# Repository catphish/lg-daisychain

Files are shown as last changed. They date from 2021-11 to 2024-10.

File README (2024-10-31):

PLEASE NOTE: THIS PROJECT HAS BEEN REPLACED BY https://github.com/catphish/ti-daisychain-bms

BMS and CAN interface for bq76PL455A
====================================

This module permits batteries with bq76PL455A based slave boards to be balanced and monitored. Communication
with the battery slave modules takes place via the proprietary daisychain interface on each battery module.
Up to 16 batteries can be connected in a chain.

The module supports the following functionality:
* Automatic balancing of all cells in the chain
* Pack and cell voltages transmitted on CAN bus
* Temperatures transmitted via CAN bus
* Balancing target can be set via CAN or standalone

Standlone Balancing
===================

With jumper CONF2 open, the module will operate in standalone balancing mode. It will regularly monitor the
voltage of all attached cells, and will bleed any cell that meets BOTH of the following conditions.

* Voltage exceeds 4.0V
* Voltage is more than 10mV higher than the voltage of the lowest cell in the pack

For thermal safety, only one cell (wit the highest voltage) per battery will be discharged at a time.

CAN Balancing
=============

With jumper CONF2 closed, balancing is controlled by CAN bus messages. The module will bleed all cells
in the pack that exceed the voltage specified in the appropriate CAN message. Balancing halts after one
second, so messages must be received at least once per second to ensure continuous balancing. CAN messages
are docuented below.

For thermal safety, only one cell (wit the highest voltage) per battery will be discharged at a time.

Monitoring
==========

In all operating modes, the total pack voltage, individual cell voltages, and battery temperatures
are transmitted on the CAN bus. This can be used for external monitoring or to allow a third party
control unit to make decisions about balancing, charging, and safety limits. CAN messages are
docuented below.

Connections
===========

The following connections should be made. Each pair of wires should be twisted together (approx 360 degrees per inch).

1.CANL - Connect this to your CAN bus. On early boards this is mislabeled CANH.
2.CNAH - Connect this to your CAN bus. On early boards this is mislabeled CANL.
3.+12v - Positive power supply. This can be connected to a normal vehicle 12v supply or any power supply between 4v and 15v.
4.GND  - Connect to your common low voltage ground.

If you are using Arduino, all 4 connections can simply go to an Arduino CAN shield.

BATT - This should be connected to the battery chain. Only pins 1 & 2 are required. They
       should be twisted together in the same way as the CAN wiring. OEM cables are compatible.

1 ------------ 1
2 ------------ 2
3              3 (Connection not required but may be beneficial to cable strength)
4              4 (Connection not required but may be beneficial to cable strength)

Jumpers
=======

CAN_TERM - This jumper should be connected if this board is the final device in your CAN bus. Connect it if you
           are connecting direcly to one other device such as an Arduino. This will connect a 120 Ohm resistor
           between CANL and CANH.

CONF1    - If you intend to use two of these devices on the CAN bus, connect this jumper on the second device.
           This will change the CAN ID to avoid conflicts.

CONF2    - CAN controlled balancing. Close this jumper to disable the default policy of 4.0V and 10mV and instead
           allow balancing to be controlled via CAN bus.

CAN Messages Transmitted
========================

The adapter will transmit CAN messages in the following format:

ID      : 0x4f0 (0x4f1 if Jumper CONF1 is connected)
Byte 0  : Module ID (0-15)
Byte 1  : Cell ID (Measurements 0-15 of each module are cell voltages)
Byte 2-3: Cell voltage where 0x0000 is 0.0v and 0xffff is 5.0v. Big endian.

ID      : 0x4f0 (0x4f1 if Jumper CONF1 is connected)
Byte 0  : Module ID (0-15)
Byte 1  : Temperature sensor ID (Measurements 16-23 of each module are temperatures)
Byte 2-3: Outer temperature of battery module. Big endian. See table below for details.

ID      : 0x4f0 (0x4f1 if Jumper CONF1 is connected)
Byte 0  : Module ID (0-15)
Byte 1  : 0xff
Byte 2-3: Balancing bitmap. Identifies which cells are currently being dissharged. LSB is cell 0.

ID      : 0x4f0 (0x4f1 if Jumper CONF1 is connected)
Byte 0  : 0xff (Module 0xff is the adapter itself)
Byte 1  : 0xfe (Measurement ID 0xfe is pack voltage)
Byte 2-5: Pack voltage where 0x0000 is 0.0v and 0xffff is 5.0v. Big endian.

ID      : 0x4f0 (0x4f1 if Jumper CONF1 is connected)
Byte 0  : 0xff (Module 0xff is the adapter itself)
Byte 1  : 0xff (Measurement ID 0xff is status)
Byte 2  : Number of modules detected
Byte 3  : Communication error counter. If a module fails to respond, this counter is incremented and the whole chain is reset.

Additional sensors
==================

ID      Info
--      ----
16      AUX7 - Unknown - probably internal battery temperature sensor. Scale unknown.
17      External NTC - negative side.
18      External NTC - positive side.
19      PCB Temerature. Scale unknown but values above 1v (13107) are safe. Balancing is disabled by the adapter below this value.
20      PCB Temerature. Scale unknown but values above 1v (13107) are safe. Balancing is disabled by the adapter below this value.
21      PCB Temerature. Scale unknown but values above 1v (13107) are safe. Balancing is disabled by the adapter below this value.
22      PCB Temerature. Scale unknown but values above 1v (13107) are safe. Balancing is disabled by the adapter below this value.
23      AUX0 - probably unused. Reads close to 0v

External NTC sesors
===================

The following calculation can be used to convert the readong for an External NTC to a temperature:

float temperature(uint16_t adc) {
  float r = 0.0000000347363427499292f * adc * adc - 0.001025770762903f * adc + 2.68235340614337f;
  float t = log(r) * -30.5280964239816f + 95.6841501312447f;
  return t;
}

This code will not work for the PCB temperature sensors and will probably not work for AUX7.

CAN Messages Received
=====================

The adapter listens for CAN messages in the following format. This message will instruct cells in all modules with a measured
voltage above the specified voltage to self-discharge for a period of 1 second. The specified voltage would usually be the
voltage of the most discharged cell in the chain. This message must be received at least once per second (2Hz recommended) to
balance continuously. Note: For thermal safety, only one cell with the highest volage in each module will be discharged at a
time, but in time, all cells will discharge to the requested voltage.

ID      : 0x4f8 (note: all adapters will act regardless of CONF1 jumper)
Byte 0  : 0x00 (Balance)
Byte 1-2: Cell voltage threshold where 0x0000 is 0.0v and 0xffff is 5.0v

The following message will attempt to reset and re-identify all modules in the chain.
ID      : 0x4f8 (note: all adapters will reset regardless of CONF1 jumper)
Byte 0  : 0x01 (Reset)

The following message will cause the module and all slave modules to sleep in a low power state until a reset message is received
ID      : 0x4f8 (note: all adapters will sleep regardless of CONF1 jumper)
Byte 0  : 0x02 (Sleep)

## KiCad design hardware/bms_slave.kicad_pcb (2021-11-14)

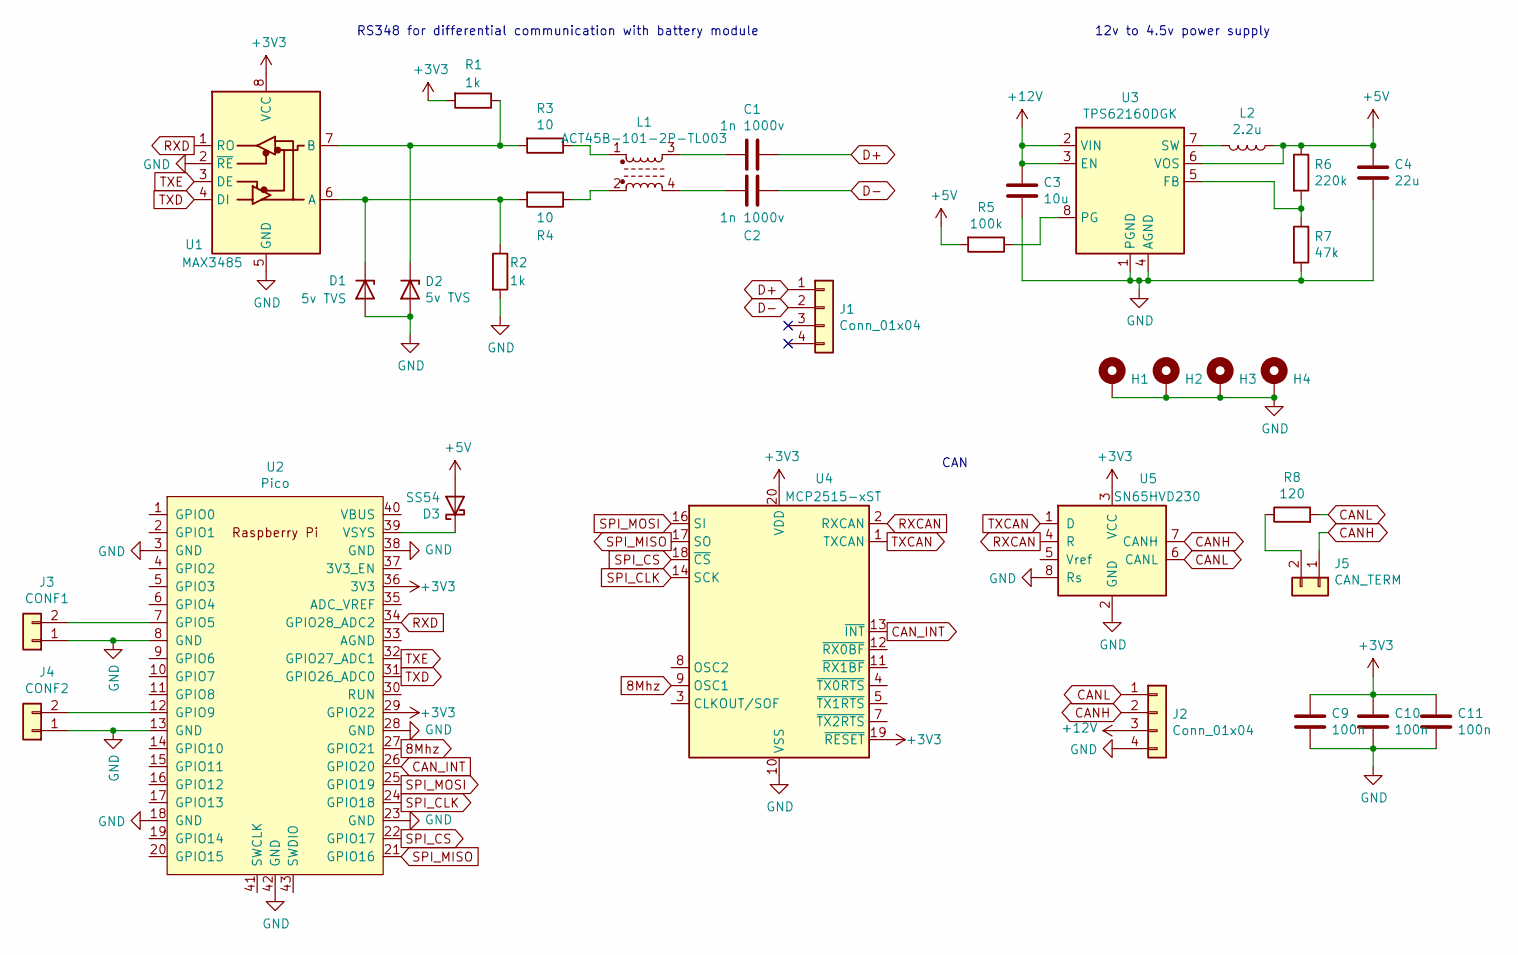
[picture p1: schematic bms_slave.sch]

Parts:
C1, C2: 1n 1000v; C_1206_3216Metric; LCSC C1941
C3: 10u; C_1210_3225Metric; LCSC C77102
C4: 22u; C_1206_3216Metric; LCSC C97950
C9, C10, C11: 100n; C_0603_1608Metric; LCSC C14663
D1, D2: 5v TVS; SOD882; LCSC C85401
D3: SS54; D_SMA; LCSC C22452
H1, H2, H3, H4: MountingHole; MountingHole_3.2mm_M3_Pad
J1, J2: Conn_01x04; SM04B1-CPTK-1A
J3: CONF1; PinHeader_1x02_P2.54mm_Vertical
J4: CONF2; PinHeader_1x02_P2.54mm_Vertical
J5: CAN_TERM; PinHeader_1x02_P2.54mm_Vertical
L1: ACT45B-101-2P-TL003; LCSC C88056
L2: 2.2u; 1227ASH100MP2; LCSC C435389
R1, R2: 1k; R_0603_1608Metric; LCSC C21190
R3, R4: 10; R_0603_1608Metric; LCSC C22859
R5: 100k; R_0603_1608Metric; LCSC C25803
R6: 220k; R_0603_1608Metric; LCSC C22961
R7: 47k; R_0603_1608Metric; LCSC C25819
R8: 120; R_1206_3216Metric; LCSC C17909
U1: MAX3485; SOP-8_3.9x4.9mm_P1.27mm; LCSC C18148
U2: Pico; RPi_Pico_SMD_TH
U3: TPS62160DGK; MSOP-8_3x3mm_P0.65mm; LCSC C60726
U4: MCP2515-xST; TSSOP-20_4.4x6.5mm_P0.65mm; LCSC C15193
U5: SN65HVD230; SOIC-8_3.9x4.9mm_P1.27mm; LCSC C12084

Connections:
8Mhz: U2.27 (GPIO21), U4.9 (OSC1)
+3V3: C9.1, C10.1, C11.1, R1.2, U1.8 (VCC), U2.29 (GPIO22), U2.36 (3V3), U4.19 (~RESET), U4.20 (VDD), U5.3 (VCC)
+5V: C4.1, D3.2 (A), L2.1, R5.2, R6.1, U3.6 (VOS)
+12V: C3.1, J2.3, U3.2 (VIN), U3.3 (EN)
CANH: J2.2, J5.1, U5.7 (CANH)
CANL: J2.1, R8.2, U5.6 (CANL)
CAN_INT: U2.26 (GPIO20), U4.13 (~INT)
D+: C1.1, J1.1
D-: C2.1, J1.2
GND: C3.2, C4.2, C9.2, C10.2, C11.2, D1.2 (A), D2.2 (A), H1.1, H2.1, H3.1, H4.1, J2.4, J3.1, J4.1, R2.2, R7.2, U1.2 (~RE), U1.5 (GND), U2.3 (GND), U2.8 (GND), U2.13 (GND), U2.18 (GND), U2.23 (GND), U2.28 (GND), U2.38 (GND), U2.42 (GND), U3.1 (PGND), U3.4 (AGND), U4.10 (VSS), U5.2 (GND), U5.8 (Rs)
unnamed: C1.2, L1.3
unnamed: C2.2, L1.4
unnamed: D1.1 (K), R2.1, R4.2, U1.6 (A)
unnamed: D2.1 (K), R1.1, R3.2, U1.7 (B)
unnamed: D3.1 (K), U2.39 (VSYS)
unnamed: J3.2, U2.7 (GPIO5)
unnamed: J4.2, U2.12 (GPIO9)
unnamed: J5.2, R8.1
unnamed: L1.1, R3.1
unnamed: L1.2, R4.1
unnamed: L2.2, U3.7 (SW)
unnamed: R5.1, U3.8 (PG)
unnamed: R6.2, R7.1, U3.5 (FB)
RXCAN: U4.2 (RXCAN), U5.4 (R)
RXD: U1.1 (RO), U2.34 (GPIO28_ADC2)
SPI_CLK: U2.24 (GPIO18), U4.14 (SCK)
SPI_CS: U2.22 (GPIO17), U4.18 (~CS)
SPI_MISO: U2.21 (GPIO16), U4.17 (SO)
SPI_MOSI: U2.25 (GPIO19), U4.16 (SI)
TXCAN: U4.1 (TXCAN), U5.1 (D)
TXD: U1.4 (DI), U2.31 (GPIO26_ADC0)
TXE: U1.3 (DE), U2.32 (GPIO27_ADC1)

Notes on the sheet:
RS348 for differential communication with battery module
12v to 4.5v power supply
CAN

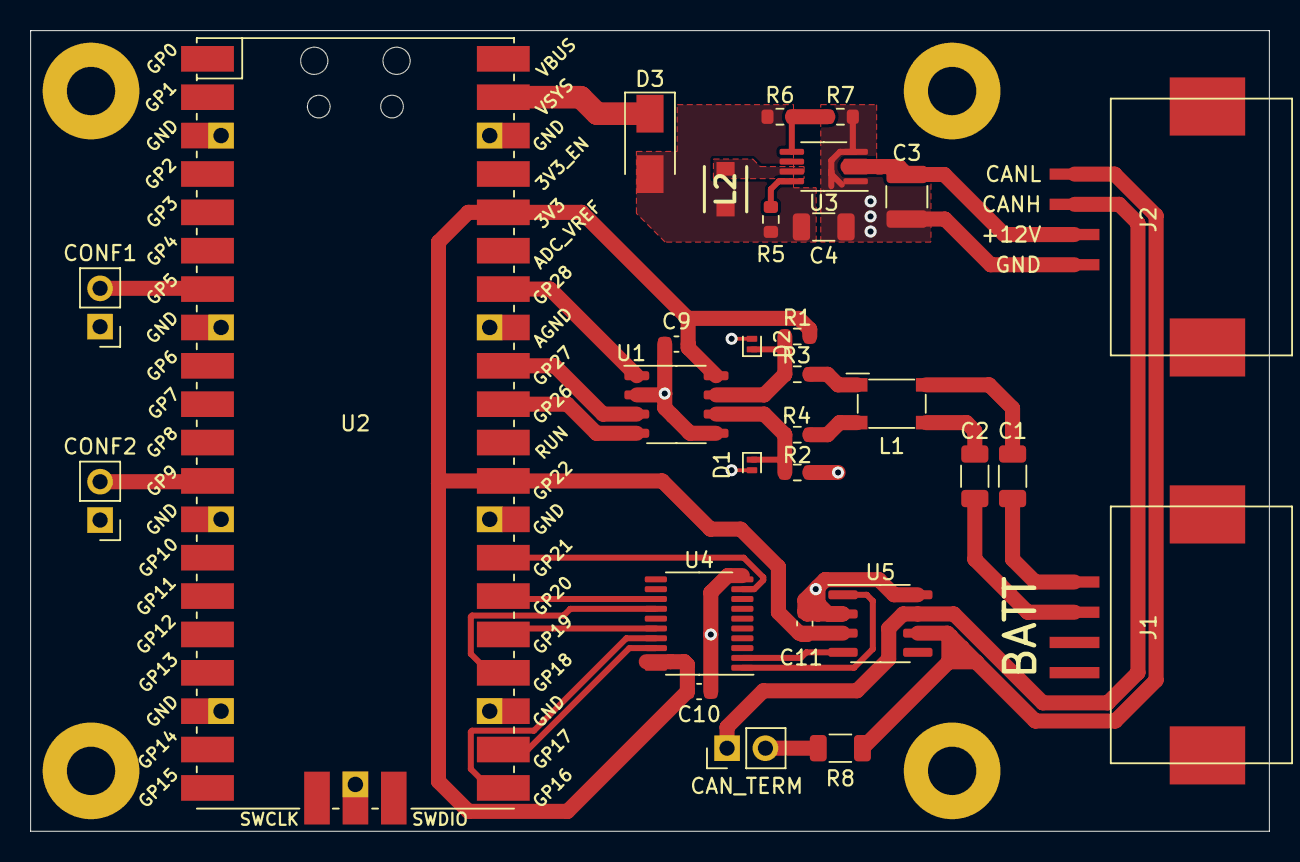
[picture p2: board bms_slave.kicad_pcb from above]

Board: 2 copper layers, 82.0 x 53.0 mm, 34 parts (0 on the bottom side), 32 nets.

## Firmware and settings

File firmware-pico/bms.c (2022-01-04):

#include <stdio.h>
#include "pico/stdlib.h"
#include "hardware/pio.h"
#include "hardware/spi.h"
#include "bms.pio.h"
#include "can.h"
#include <math.h>

// Min difference to enable balancing. 131 = 10mV
#define BALANCE_DIFF 131
// Min absolute voltage to enable balancing. 52428 = 4.0V, 53738 = 4.1V, 54525 = 4.16V
#define BALANCE_MIN 52428

// Define pins for SPI (to CAN)
#define SPI_PORT spi0
#define SPI_MISO 16
#define SPI_CS   17
#define SPI_CLK  18
#define SPI_MOSI 19
#define CAN_CLK  21 // 8MHz clock for CAN

// Define config pins
#define CONF1 5
#define CONF2 9

// Define pins for RS485 transceiver
#define SERIAL_IN     28
#define SERIAL_MASTER 27
#define SERIAL_OUT    26

// Buffers for received data
uint8_t rx_data_buffer[128];
uint8_t can_data_buffer[16];

// Other global variables
uint8_t module_count = 0;
uint8_t error_count = 0;
uint16_t balance_threshold = 0;
uint16_t cell_voltage[16][16];
uint16_t aux_voltage[16][8];
uint16_t balance_bitmap[16];
uint8_t balancing_mode;
uint16_t can_address;
uint8_t sleep_mode;
uint32_t pack_voltage;

// Variables for balancing process
uint16_t max_voltage;
uint16_t min_voltage;

// Timer
uint32_t sleep_period; // Time until next loop execution
uint8_t rewake;        // Whether the modules need to be woken up on next execution

// PIO and state machine selection
PIO pio = pio0;
#define SM_TX 0
#define SM_RX 1
#define SM_SQ 2

void SPI_configure() {
  spi_init(SPI_PORT, 1000000);
  spi_set_format(SPI_PORT, 8, 0,0,SPI_MSB_FIRST);
  gpio_set_function(SPI_MISO, GPIO_FUNC_SPI);
  gpio_set_function(SPI_MOSI, GPIO_FUNC_SPI);
  gpio_set_function(SPI_CLK, GPIO_FUNC_SPI);
  gpio_init(SPI_CS);
  gpio_set_dir(SPI_CS, GPIO_OUT);
  gpio_put(SPI_CS, 1);
}

void CAN_reset() {
  gpio_put(SPI_CS, 0);
  spi_write_blocking(SPI_PORT, (uint8_t[]){CMD_RESET},1);
  gpio_put(SPI_CS, 1);
  busy_wait_us(100);
}

uint8_t CAN_reg_read(uint8_t reg) {
  uint8_t data;
  gpio_put(SPI_CS, 0);
  spi_write_blocking(SPI_PORT, (uint8_t[]){CMD_READ, reg}, 2);
  spi_read_blocking(SPI_PORT, 0, &data, 1);
  gpio_put(SPI_CS, 1);
  return(data);
}

void CAN_reg_write(uint8_t reg, uint8_t val) {
  gpio_put(SPI_CS, 0);
  spi_write_blocking(SPI_PORT, (uint8_t[]){CMD_WRITE, reg, val}, 3);
  gpio_put(SPI_CS, 1);
}

void CAN_reg_modify(uint8_t reg, uint8_t mask, uint8_t val) {
  gpio_put(SPI_CS, 0);
  busy_wait_us(2);
  spi_write_blocking(SPI_PORT, (uint8_t[]){CMD_MODIFY, reg, mask, val}, 4);
  busy_wait_us(2);
  gpio_put(SPI_CS, 1);
}

void CAN_configure(uint16_t id) {
  // Configure speed to 500kbps based on 8MHz Crystal
  // Magic constants from https://github.com/sandeepmistry/arduino-CAN/blob/master/src/MCP2515.cpp
  CAN_reg_write(REG_CNF1, 0x00);
  CAN_reg_write(REG_CNF2, 0x90);
  CAN_reg_write(REG_CNF3, 0x02);

  // Enable Filters
  CAN_reg_write(REG_RXBnCTRL(0), 1<<2); // Enable rollover from BUF0 to BUF1
  CAN_reg_write(REG_RXBnCTRL(1), 0);
  // Set masks for RXB0 and RXB1 the same
  for(int n=0; n<2; n++) {
    uint16_t mask = 0x7ff;
    CAN_reg_write(REG_RXMnSIDH(n), mask >> 3);
    CAN_reg_write(REG_RXMnSIDL(n), mask << 5);
    CAN_reg_write(REG_RXMnEID8(n), 0);
    CAN_reg_write(REG_RXMnEID0(n), 0);
  }
  // Set match ID for all filters the same
  for(int n=0; n<6; n++) {
    CAN_reg_write(REG_RXFnSIDH(n), id >> 3);
    CAN_reg_write(REG_RXFnSIDL(n), id << 5);
    CAN_reg_write(REG_RXFnEID8(n), 0);
    CAN_reg_write(REG_RXFnEID0(n), 0);
  }

  // Set normal operation mode
  CAN_reg_write(REG_CANCTRL, MODE_NORMAL);
}

uint8_t CAN_receive(uint8_t * can_rx_data) {
  uint8_t intf = CAN_reg_read(REG_CANINTF);
  uint8_t rtr;
  uint8_t n; // One of two receive buffers
  if(intf & FLAG_RXnIF(0)) {
    n = 0;
  } else if (intf & FLAG_RXnIF(1)) {
    n = 1;
  } else {
    return 0;
  }
  rtr = (CAN_reg_read(REG_RXBnSIDL(n)) & FLAG_SRR) ? true : false;
  uint8_t dlc = CAN_reg_read(REG_RXBnDLC(n)) & 0x0f;

  uint8_t length;
  if (rtr) {
    length = 0;
  } else {
    length = dlc;

    for (int i = 0; i < length; i++)
      can_rx_data[i] = CAN_reg_read(REG_RXBnD0(n) + i);
  }

  CAN_reg_modify(REG_CANINTF, FLAG_RXnIF(n), 0x00);
  return(length);
}

void CAN_transmit(uint16_t id, uint8_t* data, uint8_t length) {
  CAN_reg_write(REG_TXBnSIDH(0), id >> 3); // Set CAN ID
  CAN_reg_write(REG_TXBnSIDL(0), id << 5); // Set CAN ID
  CAN_reg_write(REG_TXBnEID8(0), 0x00);    // Extended ID
  CAN_reg_write(REG_TXBnEID0(0), 0x00);    // Extended ID

  CAN_reg_write(REG_TXBnDLC(0), length);   // Frame length

  for (int i = 0; i < length; i++) {       // Write the frame data
    CAN_reg_write(REG_TXBnD0(0) + i, data[i]);
  }

  CAN_reg_write(REG_TXBnCTRL(0), 0x08);    // Start sending
  busy_wait_us(1000); // Allow up to 1ms to transmit
  CAN_reg_write(REG_TXBnCTRL(0), 0);    // Stop sending
  CAN_reg_modify(REG_CANINTF, FLAG_TXnIF(0), 0x00); // Clear interrupt flag
}

// Calculate message CRC.
uint16_t crc16(uint8_t * message, uint8_t length) {
  uint16_t crc = 0;
  uint16_t j;
  while (length--) {
    crc ^= *message++;
    for (j=0; j<8; j++) {
      crc = (crc >> 1) ^ ((crc & 1) ? 0xa001 : 0);
    }
  }
  return crc;
}

// Deactivate the TX PIO and send a square wave to wake up the device
void wakeup() {
  // Disable TX PIO
  pio_sm_set_enabled(pio, SM_TX, false);
  // Wait for it to be disabled
  busy_wait_ms(10);
  // Loop for 200 x 10us = 2ms
  for(int n=0; n<200; n++) {
    pio_sm_set_pins(pio, SM_TX, (1<<SERIAL_MASTER) | (0<<SERIAL_OUT)); // Drive DO low (DE enabled)
    busy_wait_us(4);
    pio_sm_set_pins(pio, SM_TX, (1<<SERIAL_MASTER) | (1<<SERIAL_OUT)); // Drive DO high (DE enabled)
    busy_wait_us(4);
  }
  pio_sm_set_pins(pio, SM_TX, (1<<SERIAL_MASTER) | (0<<SERIAL_OUT)); // Drive DO low (DE enabled)
  busy_wait_us(4);
  // Disable DE, stop driving bus
  pio_sm_set_pins(pio, SM_TX, 0);
  // Re-enable TX PIO
  pio_sm_set_enabled(pio, SM_TX, true);
  // Give the modules time to reset
  busy_wait_ms(200);
}

// Send a command string
void send_command(uint8_t* command, uint8_t length) {
  // Append framing but to the first byte and send it
  pio_sm_put_blocking(pio, SM_TX, command[0] | 0x100);
  // Send remaining bytes
  for(int n=1; n<length; n++)
    pio_sm_put_blocking(pio, SM_TX, command[n]);
  // Calculate and send CRC16
  uint16_t crc = crc16(command, length);
  pio_sm_put_blocking(pio, SM_TX, crc & 0xFF);
  pio_sm_put_blocking(pio, SM_TX, crc >> 8);
  busy_wait_us(20); // Always insert a short pause after sending commands
}

// Receive data from PIO into a local buffer, size limit and timeout in microseconds specified
// It's probably unnecessary to do this with an interrupt because we know when we expect to receive data
uint16_t receive_data(uint8_t* buffer, uint16_t size, uint32_t timeout) {
  uint16_t rx_data_offset = 0;
  // Return immediately if size is zero
  if(size == 0) return 0;
  // Loop until timeout expires
  for(int n=0; n<timeout; n++) {
    // Check for data in input FIFO
    while(!pio_sm_is_rx_fifo_empty(pio, SM_RX)) {
      // Receive one byte
      buffer[rx_data_offset++] = pio_sm_get_blocking(pio, SM_RX);
      // Return full size if we've filled the string
      if(rx_data_offset == size) return size;
    }
    // Sleep 1 microsecond each loop
    busy_wait_us(1);
  }
  // Return partial length received
  return rx_data_offset;
}

// Configure all daisychained packs with sequential addresses
void configure() {
  // Fully Enable Differential Interfaces and Select Auto-Addressing Mode
  send_command((uint8_t[]){0xF2,0x10,0x10,0xE0}, 4);
  // Configure the bq76PL455A-Q1 device to use auto-addressing to select address
  send_command((uint8_t[]){0xF1,0x0E,0x10}, 3);
  // Configure the bq76PL455A-Q1 device to enter auto-address mode
  send_command((uint8_t[]){0xF1,0x0C,0x08}, 3);
  // Configure 16 devices with sequential addresses
  for(int n=0; n<16; n++) {
    send_command((uint8_t[]){0xF1,0x0A,n}, 3);
  }
  for(int n=0; n<16; n++) {
    // Attempt to read back the address from each device
    pio_sm_clear_fifos(pio, SM_RX);
    send_command((uint8_t[]){0x81,n,0x0A,0x00}, 4);
    uint16_t received = receive_data(rx_data_buffer, 4, 10000);
    // If we don't receive a response, assume there are no more modules
    // and return the number of modules successfully found.
    if(received != 4) {
      module_count = n;
      return;
    }
  }
  module_count = 16;
}

// Request that all packs simultaneously sample voltage
void sample_all() {
  // 0xFF 0xFF 0xFF - these 24 bits enable sampling of 16 cell voltages and
  //                  8 AUX channels. Some will contain temperature data.
  //                  16x oversampling.
  send_command((uint8_t[]){0xF6,0x02,0x00,0xFF,0xFF,0xFF,0x00,0x04}, 8);
  busy_wait_ms(10);
}

// Put all modules to sleep
void sleep_modules() {
  send_command((uint8_t[]){0xF1,0x0C,0x48}, 3);
  rewake = 1;
}

// Return 1 if all PCB temperature sensors on a module are above 1.0v
uint8_t pcb_below_temp(uint8_t module) {
  if(aux_voltage[module][3] < 13107) return 0;
  if(aux_voltage[module][4] < 13107) return 0;
  if(aux_voltage[module][5] < 13107) return 0;
  if(aux_voltage[module][6] < 13107) return 0;
  return 1;
}

float temperature(uint16_t adc) {
  float r = adc;
  r = r * r * 0.0000000347363427499292f - r * 0.001025770762903f + 2.68235340614337f;
  float t = logf(r) * -30.5280964239816f + 95.6841501312447f;
  return t;
}

int main()
{
  // Set system clock to 80MHz, this seems like a reasonable value for the 4MHz data
  set_sys_clock_khz(80000, true);
  // Configure STDIO for debugging
	stdio_init_all();
  // Load and initialize the TX PIO program
  uint offset_tx = pio_add_program(pio, &daisychain_tx_program);
  daisychain_tx_program_init(pio, SM_TX, offset_tx, SERIAL_OUT, SERIAL_MASTER);
  // Load and initialize the RX PIO program
  uint offset_rx = pio_add_program(pio, &daisychain_rx_program);
  daisychain_rx_program_init(pio, SM_RX, offset_rx, SERIAL_IN, SERIAL_MASTER);
  // Load and initialize 8MHz square wave generator
  uint offset_sq = pio_add_program(pio, &square_wave_program);
  square_wave_program_init(pio, SM_SQ, offset_sq, CAN_CLK);

  // Configure config pins CONF1 and CONF2 as inputs with pull-up
  gpio_init(CONF1);
  gpio_set_dir(CONF1, GPIO_IN);
  gpio_pull_up(CONF1);
  gpio_init(CONF2);
  gpio_set_dir(CONF2, GPIO_IN);
  gpio_pull_up(CONF2);

  // Configure SPI to communicate with CAN
  SPI_configure();
  // Set up CAN to receive messages
  CAN_reset();
  CAN_configure(0x4F8);

  // Wait a little at startup
  sleep_ms(2000);

softreset:
  // By default don't enter indefinite sleep
  sleep_mode = 0;
  // Wake modules immediately
  rewake = 1;
  // Main loop.
  while (1) {
    // Set CAN address based on CONF1 input
    can_address = 0x4f0 + !gpio_get(CONF1);
    // Set balancing mode based on CONF2 input
    balancing_mode = gpio_get(CONF2);
    // Start counter for total voltage
    pack_voltage = 0;

    // If we've been sleeping, wake the modules
    if(rewake) {
      rewake = 0;
      // Wake and reset up the modules
      wakeup();
      // Configure the module addresses
      configure();
    }

    // Set discharge timeout (1s, all modules)
    send_command((uint8_t[]){ 0xF1,0x13,(1<<4) | (1<<3) }, 3);
    // Disable discharge (all modules)
    send_command((uint8_t[]){ 0xF2,0x14,0,0 }, 4);
    // Set communication timeout (10s) (all modules)
    send_command((uint8_t[]){ 0xF1,0x28,(6<<4) }, 3);

    // Send a broadcast message to all modules in chain to simultaneously sample all cells
    sample_all();

    // Collect voltages and set balancing on up to 16 modules
    // We want to complete this loop as fast as possible because balancing must be disabled during measurement
    max_voltage = 0;
    min_voltage = 65535;
    for(int module = 0; module < module_count; module++) {
      // Clear the input FIFO just in case
      pio_sm_clear_fifos(pio, SM_RX);
      // Request sampled voltage data from module
      send_command((uint8_t[]){0x81,module,0x02,0x20}, 4);
      // Receive response data from PIO FIFO into CPU buffer - 51 bytes of data with 10ms timeout
      // 24 values * 2 bytes + length + 2 byte checksum = 51
      uint16_t received = receive_data(rx_data_buffer, 51, 10000);
      // TODO: check RX CRC here
      if(received == 51) {
        balance_bitmap[module] = 0;
        uint16_t max_v = 0;
        for(int cell=0; cell<16; cell++) {
          // nb. Cells are in reverse, cell 16 is reported first
          cell_voltage[module][cell] = rx_data_buffer[(15-cell)*2+1] << 8 | rx_data_buffer[(15-cell)*2+2];
          pack_voltage += cell_voltage[module][cell];
          if(cell_voltage[module][cell] > max_voltage) max_voltage = cell_voltage[module][cell];
          if(cell_voltage[module][cell] < min_voltage) min_voltage = cell_voltage[module][cell];
          // Balancing
          if(pcb_below_temp(module)) // Don't balance if PCB is hot
            if(balance_threshold) // Don't balance unless threshold set
              if(cell_voltage[module][cell] > balance_threshold) // Compare cell voltage to threshold
                if(cell_voltage[module][cell] > max_v) { // Only balance the highest voltage cell
                  balance_bitmap[module] = (1 << cell); // Only ever balance one cell
                  max_v = cell_voltage[module][cell];
                }
        }
        for(int aux=0; aux<8; aux++) {
          aux_voltage[module][aux] = rx_data_buffer[(16+aux)*2+1] << 8 | rx_data_buffer[(16+aux)*2+2];
        }
        send_command((uint8_t[]){ 0x92,module,0x14,balance_bitmap[module] >> 8, balance_bitmap[module] }, 5);
      } else {
        printf("Communitcation error! Reset!\n");
        error_count++;
        goto softreset;
      }
    }

    float v = pack_voltage * 5.0f / 65535.0f; // Convert to decimal for display
    float vmin = min_voltage * 5.0f / 65535.0f; // Convert to decimal for display
    float vmax = max_voltage * 5.0f / 65535.0f; // Convert to decimal for display
    printf("PACK: %.2f | MIN: %.3f | MAX: %.3f | ", v, vmin, vmax);

    if(balancing_mode) {
      // CONF2 is set, enable standalone balancing
      if(max_voltage > BALANCE_MIN) { // 4.16V
        if(max_voltage > min_voltage + BALANCE_DIFF) { // Min cell + 10mV
          // At least one cell is above 4.16V, lets balance!
          balance_threshold = min_voltage + BALANCE_DIFF; // Min cell + 10mV
          if(balance_threshold < BALANCE_MIN) balance_threshold = BALANCE_MIN; // No less than 4.16V
          float v = balance_threshold * 5.0f / 65535.0f; // Convert to decimal for display
          printf("BALANCING: ACTIVE %.3fV\n", v);
          sleep_period = 900;
        } else {
          // Cells are balanced
          balance_threshold = 0;
          printf("BAL: BALANCED\n");
          sleep_period = 60000;
          sleep_modules();
        }
      } else {
        balance_threshold = 0;
        printf("BAL: INACTIVE\n");
          sleep_period = 60000;
          sleep_modules();
      }
    } else {
      // CONF2 is not set, await balancing instructions from CAN
      // CAN mode will drain both the HV and LV batteries as it will poll every
      // second regardless of balancing state and never shuts down the modules.
      sleep_period = 900;

      float v = balance_threshold * 5.0f / 65535.0f; // Convert to decimal for display
      printf("BAL: CAN %.3fV\n", v);
      balance_threshold = 0;
    }

    // Loop through all modules again to process data
    for(int module = 0; module < module_count; module++) {
      // Send cell voltages
      printf("M%2.2i ", module);
      for(int cell=0; cell<16; cell++) {
        float v = cell_voltage[module][cell] * 5.0f / 65535.0f;
        if(balance_bitmap[module] & (1<<cell))
          printf("%.3f* ", v);
        else
          printf("%.3f  ", v);
        if(cell == 7) printf("%.1fC\n    ", temperature(aux_voltage[module][1]));
      }
      printf("%.1fC\n", temperature(aux_voltage[module][2]));
    }

    // Send general status information to CAN
    CAN_transmit(can_address, (uint8_t[]){ 0xff, 0xff, module_count, error_count }, 4);
    CAN_transmit(can_address, (uint8_t[]){ 0xff, 0xfe, pack_voltage>>24, pack_voltage>>16, pack_voltage>>8, pack_voltage}, 4);
    // Loop through all modules again to send data to CAN
    for(int module = 0; module < module_count; module++) {
      // Transmit balancing bitmap by CAN
      CAN_transmit(can_address, (uint8_t[]){ module, 0xff, balance_bitmap[module] >> 8, balance_bitmap[module] }, 4);

      // Transmit cell voltages by CAN
      for(int cell=0; cell<16; cell++)
        CAN_transmit(can_address, (uint8_t[]){ module, cell, cell_voltage[module][cell] >> 8, cell_voltage[module][cell] }, 4);

      // Transmit AUX inputs (temp sensors) by CAN
      for(int aux=0; aux<8; aux++)
        CAN_transmit(can_address, (uint8_t[]){ module, 16 + aux, aux_voltage[module][aux] >> 8, aux_voltage[module][aux] }, 4);
    }

    // Low power sleep
    if(balancing_mode) {
      sleep_ms(sleep_period);
    } else {
      uint32_t t0 = time_us_32();
      // Sleep for 900ms or forever if sleep_mode is set
      while(sleep_mode || (time_us_32() - t0 < (sleep_period * 1000))) {
        if(CAN_receive(can_data_buffer)) {
          // Set balance target
          if(can_data_buffer[0] == 0) balance_threshold = (can_data_buffer[1] << 8) | can_data_buffer[2];
          // Reset and wake modules
          if(can_data_buffer[0] == 1) goto softreset;
          // Sleep all modules and wait for reset
          if(can_data_buffer[0] == 2) {
            sleep_modules();
            sleep_mode = 1;
          }
        }
        // Wake MCU to check CAN messages every 2ms
        sleep_ms(2);
      }
    }
  }
}

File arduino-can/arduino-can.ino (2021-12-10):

#include <CAN.h>

void setup() {
  Serial.begin(1000000);
  CAN.begin(500000);
  CAN.onReceive(onReceive);
}

// Call this a couple of times per second for continuous balancing
void balance(float voltage) {
  uint16_t v = voltage * 65535.0f / 5.0f;
  CAN.beginPacket(0x4F8);
  CAN.write(0x00); // Balance
  CAN.write(v >> 8);
  CAN.write(v);
  CAN.endPacket();
}

void loop() {
  delay(500);
  // This program is current set up to balance to 3.8v all the time for testing.

  // You probably want to delect the lowest cell voltage in the pack and set this
  // a couple of mV higher than the detected minimum.

  // You probably also only want to balance above a specified maximum voltage so
  // that you are only top balancing.

  balance(3.8);
}

// Calculate NTC temperature
float temperature(uint16_t adc) {
  float r = 0.0000000347363427499292f * adc * adc - 0.001025770762903f * adc + 2.68235340614337f;
  float t = log(r) * -30.5280964239816f + 95.6841501312447f;
  return t;
}

// Calculate ADC voltage
float voltage(uint16_t adc) {
  float v = adc * 5.0f / 65535.0f;
  return v;
}

// Called when CAN data is received
void onReceive(int packetSize) {
  if(CAN.packetRtr()) return;         // Ignore rtr packets
  if((CAN.packetId() & 0xfffffffe) != 0x4f0) return; // Ignore non-BMS packets

  uint8_t module = CAN.read();
  uint8_t cell = CAN.read();
  uint16_t data = (uint16_t)CAN.read() << 8 | CAN.read();
  if(module == 0xff) {
    Serial.print("M:");
    Serial.print(module);
    Serial.print(" C:");
    Serial.print(cell);
    Serial.println(" pack data");
  } else {
    if(cell < 16) {
      Serial.print("M:");
      Serial.print(module);
      Serial.print(" C:");
      Serial.print(cell);
      Serial.print(" ");
      Serial.print(voltage(data), 3);
      Serial.print("V\n");
    } else if(cell == 17) {
      Serial.print("M:");
      Serial.print(module);
      Serial.print(" NEG SIDE TEMP: ");
      Serial.print(temperature(data), 2);
      Serial.print("C\n");
    } else if(cell == 18) {
      Serial.print("M:");
      Serial.print(module);
      Serial.print(" POS SIDE TEMP: ");
      Serial.print(temperature(data), 2);
      Serial.print("C\n");
    } else if(cell == 0xff) {
      Serial.print("M:");
      Serial.print(module);
      Serial.print(" Balancing cells: ");
      Serial.print(data, HEX);
      Serial.print("\n");
    }
  }
}

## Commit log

2021-11-06 initial commit of example arduino master and documentation
2021-11-08 add correct arduino file
2021-11-14 add hardware and firmware sources
    [bms_slave.kicad_pcb, bms_slave.sch]
2021-12-06 low power sleep when not balancing
2021-12-06 print error message on communication error condition
    [bms.c]
2021-12-06 replace long busy wait with low power sleep
    [bms.c]
2021-12-10 invert mode jumper, fix pack voltage display
    [bms.c]
2021-12-10 add arduino CAN exaple and update documentation for dual mode firmware
